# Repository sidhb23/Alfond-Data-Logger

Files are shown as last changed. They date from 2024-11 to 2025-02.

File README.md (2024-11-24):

# Alfond-Data-Logger

Capstone Project of Alex Picard and Siddhartha Bajracharya.

The project is a custom PCB designed to monitor the Ice and Ambient temperature/humidity of the Alfond Sports Arena. This repository contains the code for the STM32U545VET6 microcontroller used in the custom PCB. It also contains the schematic and layout files of the designed PCB. 

A python script is also included which is used to receive/send data from a Raspberry Pi to the PCB through Zigbee

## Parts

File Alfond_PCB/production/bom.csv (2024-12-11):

Designator | Footprint | Quantity | Value | LCSC Part #
_7, _6, _5, _4, _3, _2, |  | 7
BRD1 | 128x64OLED | 1 | SSD1306
C1 | 0603 | 1 | 4u7
C10, C14, C2, C3, C4, C5, C6, C7, C8, C9 | 0402 | 10 | 100n
C11, C12 | 0402 | 2 | 10p
C13 | 0805 | 1 | 10u
C15 | 0805 | 1 | 2.2u
D1, D2 | SOT-23-5 | 2 | SOT-23-5
D3 | 0603 | 1 | RED
D4 | 0805 | 1 | RED
INA+, INA- | PinHeader_1x01_P2.54mm_Vertical | 2 | PinHeader_1x01_P2.54mm_Vertical
INA260 | 1X08_ROUND_70 | 1 | 1X08_ROUND_70
J3 | PinHeader_1x05_P2.54mm_Vertical | 1 | Conn_01x05_Pin
J5 | USB_Micro-B_Wuerth_629105150521 | 1 | USB_B_Micro
MOD1 | XBEE-20_THT | 1 | XB24CZ7PIT-004 | XB24CZ7PIT-004
MS8607 | 1X05_ROUND | 1 | 1X05_ROUND
P1 | JST_PHR-2 | 1 | PHR-2
R1 | 0402 | 1 | 4.7k
R3 | 0402 | 1 | 1k
R4, R5 | 0402 | 2 | 10k
R6, R7 | 0402 | 2 | 1.5k
S1, S2 | Switch_Tactile_THT_B3F-1xxx | 2 | PTS645SM43SMTR92_LFS | PTS645SM43SMTR92 LFS
SW1 | SW_SPDT_PCM12 | 1 | SW_SPDT
U1 | TO-92_Inline | 1 | DS18B20
U2 | LQFP-100_14x14mm_P0.5mm | 1 | STM32U545VETx
U5 | SOT-23-5_M5_MCH | 1 | MIC5219-3.3YM5-TR
Y1 | Crystal_SMD_3225-4Pin_3.2x2.5mm | 1 | 16MHz

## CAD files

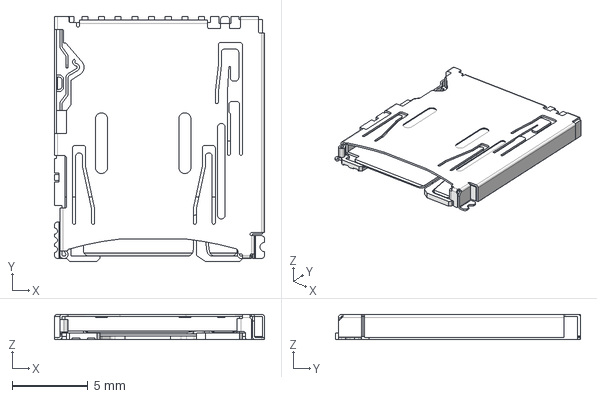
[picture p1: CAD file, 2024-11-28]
Alfond_PCB/Models/DM3AT-SF-PEJM5.stp
13.8 x 16.2 x 1.68 mm

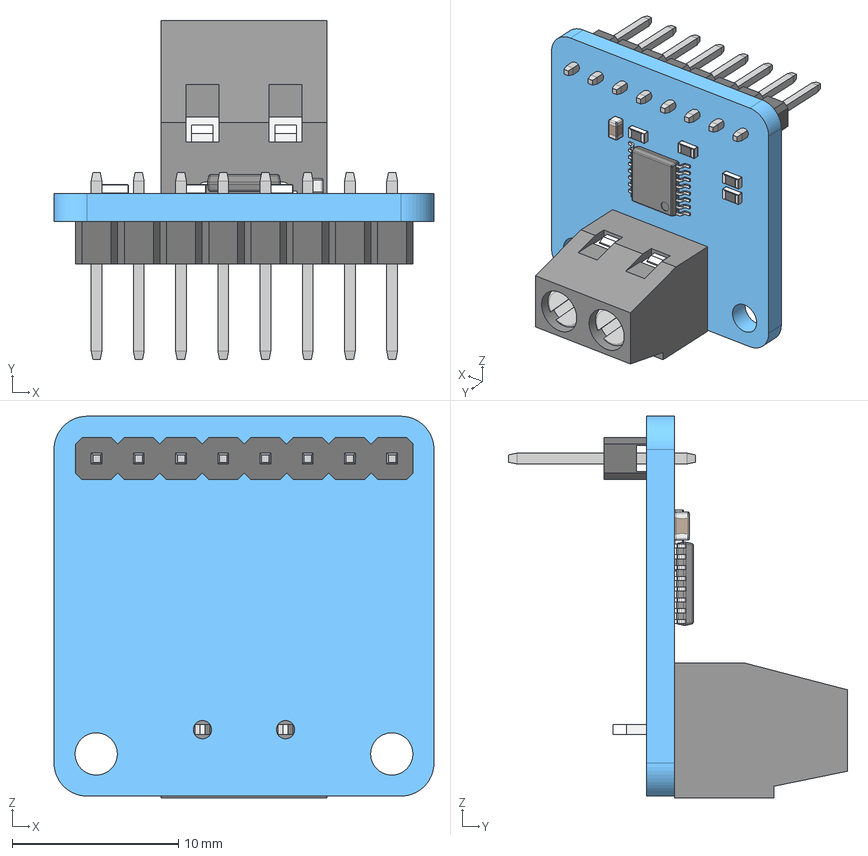
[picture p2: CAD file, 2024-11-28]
Alfond_PCB/Models/Adafruit INA260 Breakout Board.step
22.9 x 20.4 x 23.0 mm
PCB
BODY-TSSOP
LEAD-TSSOP x 16
Resistor x 4
Capacitor
Screw Terminal Block
1x8 Male Headers

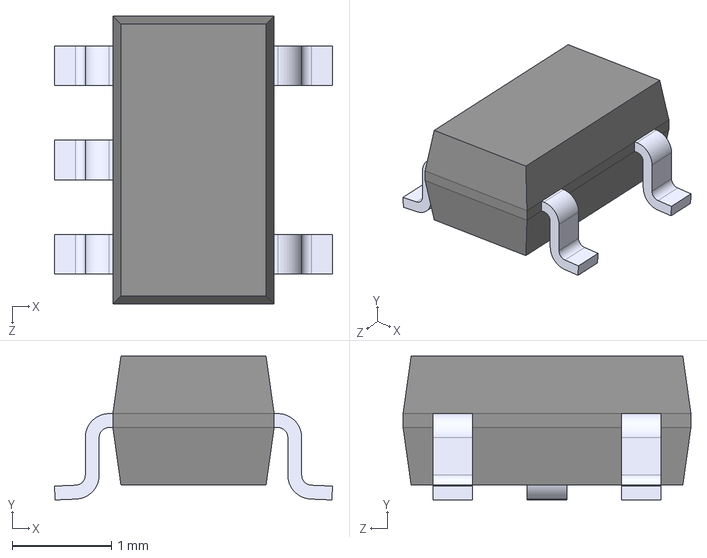
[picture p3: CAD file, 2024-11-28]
Alfond_PCB/Footprints/MAX40200AUK_T/MAX40200AUK_T.step
2.80 x 1.45 x 2.90 mm

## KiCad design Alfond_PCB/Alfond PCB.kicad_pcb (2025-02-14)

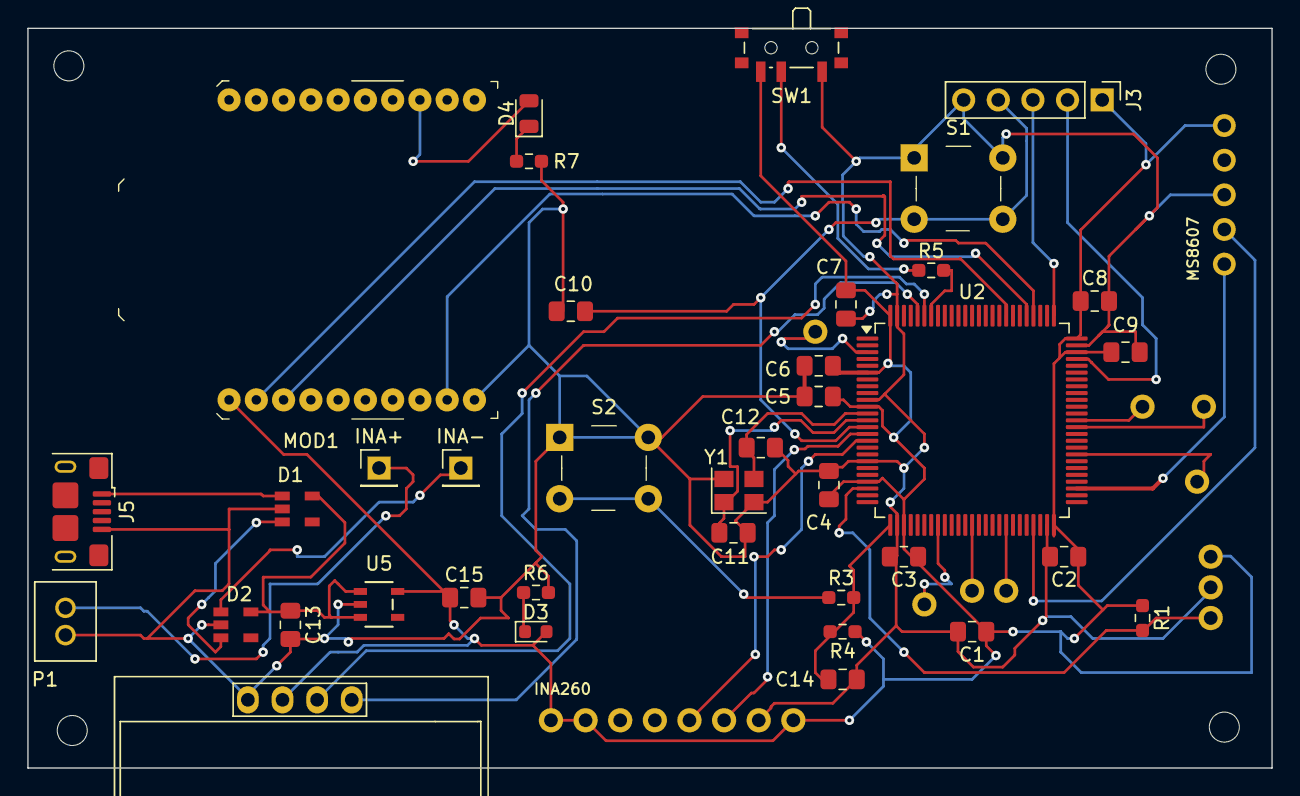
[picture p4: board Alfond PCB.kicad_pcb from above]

Board: 2 copper layers, 91.2 x 54.2 mm, 44 parts (0 on the bottom side), 29 nets.

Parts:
Brd1: SSD1306; 128x64OLED
C1: 4u7; C_0805_2012Metric_Pad1.18x1.45mm_HandSolder
C2, C3, C4, C5, C6, C7, C8, C9, C10, C14: 100n; C_0805_2012Metric_Pad1.18x1.45mm_HandSolder
C11, C12: 10p; C_0805_2012Metric_Pad1.18x1.45mm_HandSolder
C13: 10u; C_0805_2012Metric_Pad1.18x1.45mm_HandSolder
C15: 2.2u; C_0805_2012Metric_Pad1.18x1.45mm_HandSolder
D1, D2: SOT-23-5
D3: RED; LED_0603_1608Metric
D4: RED; LED_0805_2012Metric
H1, H2, H3, H4: MountingHole; MountingHole_2.2mm_M2
INA260: 1X08_ROUND_70
INA+: PinHeader_1x01_P2.54mm_Vertical
INA-: PinHeader_1x01_P2.54mm_Vertical
J3: Conn_01x05_Pin; PinHeader_1x05_P2.54mm_Vertical
J5: USB_B_Micro; USB_Micro-B_Amphenol_10118193-0001LF_Horizontal
MOD1: XB24CZ7PIT-004; XBEE-20_THT
MS8607: 1X05_ROUND
P1: PHR-2; JST_PHR-2
R1: 4.7k; R_0603_1608Metric_Pad0.98x0.95mm_HandSolder
R3: 1k; R_0603_1608Metric_Pad0.98x0.95mm_HandSolder
R4, R5: 10k; R_0603_1608Metric_Pad0.98x0.95mm_HandSolder
R6, R7: 1.5k; R_0603_1608Metric_Pad0.98x0.95mm_HandSolder
S1, S2: PTS645SM43SMTR92_LFS; Switch_Tactile_THT_B3F-1xxx
SW1: SW_SPDT; SW_SPDT_PCM12
U2: STM32U545VETx; LQFP-100_14x14mm_P0.5mm
U5: MIC5219-3.3YM5-TR; SOT-23-5_M5_MCH
Y1: 16MHz; Crystal_SMD_3225-4Pin_3.2x2.5mm

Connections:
+3.3V: Brd1.2 (VCC), C1.1, C2.1, C3.1, C4.1, C5.1, C6.1, C7.1, C8.1, C9.1, C15.1, D3.2 (A), INA260.8, INA260.Vin+, INA260.Vin-, J3.1, MOD1.1 (Vcc), MS8607.5, R1.1, R4.1, SW1.3 (C), U2.6 (VBAT), U2.11 (VDD), U2.22 (VDDA), U2.28 (VDD), U2.50 (VDD), U2.73 (VDDUSB), U2.75 (VDD), U2.100 (VDD), U5.5 (OUT)
/BOOT0: R5.2, U2.94 (PH3)
/GPIO_INPUT_Button: C14.1, R3.2, R4.2, U2.26 (PA3)
/GPIO_SLEEP_XBEE: MOD1.9 (~DTR/SLRQ/DI8), U2.79 (PC11)
/HSE_IN: C12.1, U2.12 (PH0), Y1.3
/HSE_OUT: C11.1, U2.13 (PH1), Y1.1
/I2C1_SCL: Brd1.3 (SCL), U2.95 (PB8)
/I2C1_SDA: Brd1.4 (SDA), U2.96 (PB9)
/I2C2_SCL: MS8607.2, U2.47 (PB10)
/I2C2_SDA: MS8607.1, U2.53 (PB14)
/I2C3_SCL: INA260.6, U2.15 (PC0)
/I2C3_SDA: INA260.5, U2.16 (PC1)
/INA+: INA+.1, P1.2
/INA-: D2.1, INA-.1
/NRST: C10.1, J3.4, S1.3, S1.4, U2.14 (NRST)
/PWR_LED_K: D3.1 (K), R6.1
/PWR_LED_K2: D4.1 (K), R7.1
/SWD_CLK: J3.3, U2.76 (PA14)
/SWD_DIO: J3.2, U2.72 (PA13)
/UART4_TX: R1.2, U2.23 (PA0)
/UART5_RX: MOD1.2 (DOUT), U2.83 (PD2)
/UART5_TX: MOD1.3 (DIN/~Config), U2.80 (PC12)
/V_USB: D1.1, J5.1 (VBUS)
EN: D1.3, D2.3
GND: Brd1.1 (GND), C1.2, C2.2, C3.2, C4.2, C5.2, C6.2, C7.2, C8.2, C9.2, C10.2, C11.2, C12.2, C13.2, C14.2, C15.2, D1.2, D2.2, INA260.7, J3.5, J5.5 (GND), MOD1.10 (GND), MS8607.3, P1.1, R6.2, R7.2, S1.1, S1.2, S2.1, S2.2, SW1.1 (A), U2.10 (VSS), U2.19 (VSSA), U2.27 (VSS), U2.49 (VSS), U2.74 (VSS), U2.99 (VSS), U5.2 (GND), Y1.2, Y1.4
unnamed: C13.1, D1.5, D2.5, U5.1 (IN), U5.3 (EN)
unnamed: D4.2 (A), MOD1.13 (ON/~SLEEP)
unnamed: R3.1, S2.3, S2.4
unnamed: R5.1, SW1.2 (B)

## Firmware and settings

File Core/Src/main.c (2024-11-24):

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
/* Includes ------------------------------------------------------------------*/
#include "main.h"

/* USER CODE BEGIN Includes */
#include "ssd1306.h"
#include "ms8607.h"
#include <stdio.h>
#include <string.h>
/* USER CODE END Includes */

/* USER CODE BEGIN PD */
#define MS8607_ADDRESS 0x76

// Command Definitions
#define CMD_READ_PROM 0xA0
#define CMD_READ_TEMP 0x58
#define CMD_READ_PRESS 0x40
#define CMD_RESET 0x1E

#define INA260_I2C_ADDRESS  0x40 << 1
#define REG_CURRENT         0x01
#define REG_BUS_VOLTAGE     0x02
#define REG_POWER           0x03
/* USER CODE END PD */


I2C_HandleTypeDef hi2c1;
I2C_HandleTypeDef hi2c2;
I2C_HandleTypeDef hi2c3;

UART_HandleTypeDef huart4;
UART_HandleTypeDef huart5;
UART_HandleTypeDef huart3;

void SystemClock_Config(void);
static void SystemPower_Config(void);
static void MX_GPIO_Init(void);
static void MX_ICACHE_Init(void);
static void MX_I2C1_Init(void);
static void MX_I2C2_Init(void);
static void MX_UART4_Init(int baud);
static void MX_UART5_Init(void);
static void MX_USART3_UART_Init(void);
static void MX_I2C3_Init(void);

/* USER CODE BEGIN PFP */
int presence = 0, isRxed = 0;
  uint8_t RxData[8], Temp_LSB = 0, Temp_MSB = 0;
  int16_t Temp;
  float temp_DS18B20;
  void INA260_Init();
  float INA260_ReadCurrent();
  float INA260_ReadVoltage();
  float INA260_ReadPower();
/* USER CODE END PFP */

/* USER CODE BEGIN 0 */
int DS18B20_start (void)
{
		uint8_t data = 0xF0;
		MX_UART4_Init(9600);
		HAL_UART_Transmit(&huart4, &data, 1, 100);
		if (HAL_UART_Receive(&huart4, &data, 1, 1000) != HAL_OK) return -1; // failed.. check connection
		MX_UART4_Init(115200);
		if (data == 0xf0) return -2; //error no device detected
		return 1;
}

void DS18B20_Write (uint8_t data)
{
	uint8_t buffer[8];
	for (int i = 0; i < 8; i++) {
		if ((data & (1<<i)) != 0){  // if the bit is high
			buffer[i] = 0xFF; // send a 1
		} else {
			buffer[i] = 0x00; // send a 0
		}
	}

	HAL_UART_Transmit(&huart4, buffer, 8, 1000);
}

uint8_t DS18B20_Read(void)
{
    uint8_t value = 0;
    for (int i = 0; i < 8; i++)
    {
        uint8_t tx_byte = 0xFF;  // Transmit request for a read time slot
        uint8_t rx_byte = 0;

        // Transmit and receive each bit
        if (HAL_UART_Transmit(&huart4, &tx_byte, 1, 1000) != HAL_OK)
        {
            // Handle transmission error
        }

        if (HAL_UART_Receive(&huart4, &rx_byte, 1, 1000) != HAL_OK)
        {
            // Handle reception error
        }

        // Store the received bit in RxData for debugging
        RxData[i] = rx_byte;

        // Interpret received bit as 1 if rx_byte == 0xFF, otherwise 0
        if (rx_byte == 0xFF)
        {
            value |= (1 << i); // Set the bit in value
        }
    }
    return value;
}


void HAL_UART_RxCpltCallback(UART_HandleTypeDef *huart)
{
	isRxed = 1;
}
/* USER CODE END 0 */

/**
  * @brief  The application entry point.
  * @retval int
  */
int main(void)
{

  /* USER CODE BEGIN 1 */
	uint16_t prom[6];

	  char snum[15] = "Hello world";
	  double temperature;
	  float pressure;
	  float humidity;
  /* USER CODE END 1 */

  /* MCU Configuration--------------------------------------------------------*/

  /* Reset of all peripherals, Initializes the Flash interface and the Systick. */
  HAL_Init();

  /* Configure the system clock */
  SystemClock_Config();

  /* Configure the System Power */
  SystemPower_Config();

  /* Initialize all configured peripherals */
  MX_GPIO_Init();
  MX_ICACHE_Init();
  MX_I2C1_Init();
  MX_I2C2_Init();
  MX_UART4_Init(9600);
  MX_UART5_Init();
  MX_USART3_UART_Init();
  MX_I2C3_Init();
  /* USER CODE BEGIN 2 */
  SSD1306_Init();
  INA260_Init();
  /* USER CODE END 2 */

  /* Infinite loop */
  /* USER CODE BEGIN WHILE */
  while (1)
    {
	  MS8607_ReadPROM(&hi2c2, prom);
	  temperature = MS8607_ReadTemperature(&hi2c2, prom);

	    	  // Convert temperature to string for display
	    	  snprintf(snum, sizeof(snum), "%.2lf C", temperature);

	    	  // Update the display
	    	  SSD1306_GotoXY(0, 0);
	    	  SSD1306_Puts(snum, &Font_7x10, SSD1306_COLOR_WHITE);
	    	  SSD1306_UpdateScreen();
	    	  strcat(snum, "\n\r");
	    	  HAL_UART_Transmit(&huart5, (uint8_t*)snum, strlen(snum), 100);
	    	  pressure = MS8607_ReadPressure(&hi2c2, prom, temperature);
	    	  // Convert temperature to string for display
	    	  snprintf(snum, sizeof(snum), "%.2f HPa", pressure);

	    	  // Update the display
	    	  SSD1306_GotoXY(0, 20);
	    	  SSD1306_Puts(snum, &Font_7x10, SSD1306_COLOR_WHITE);
	    	  SSD1306_UpdateScreen();
	    	  strcat(snum, "\n\r");
	    	  HAL_UART_Transmit(&huart5, (uint8_t*)snum, strlen(snum), 100);
	    	  humidity = MS8607_ReadHumidity(&hi2c2);
	    	  // Convert temperature to string for display
	    	  snprintf(snum, sizeof(snum), "%.2f%%", humidity);
	    	  // Update the display
	    	  SSD1306_GotoXY(0, 40);
	    	  SSD1306_Puts(snum, &Font_7x10, SSD1306_COLOR_WHITE);
	    	  SSD1306_UpdateScreen();
	    	  strcat(snum, "\n\r");
	    	  HAL_UART_Transmit(&huart5, (uint8_t*)snum, strlen(snum), 100);
	    	  presence = DS18B20_start();
	    	  	  DS18B20_Write(0xCC); // skip ROM
	    	  	  DS18B20_Write(0x44); // convert temperature

	    	  	  presence = DS18B20_start();
	    	  	  DS18B20_Write(0xCC); // skip ROM
	    	  	  DS18B20_Write(0xBE); // read scratchpad

	    	  	  Temp_LSB = DS18B20_Read();
	    	  	  Temp_MSB = DS18B20_Read();
	    	  	  Temp = (Temp_MSB<<8) | Temp_LSB;
	    	  	  temp_DS18B20 = (float)Temp/16.0; // resolution is 0.0625
	    	  	snprintf(snum, sizeof(snum), "%.2f C Ice", temp_DS18B20);

	    	  		    	  // Update the display
	    	  		    	  SSD1306_GotoXY(50, 40);
	    	  		    	  SSD1306_Puts(snum, &Font_7x10, SSD1306_COLOR_WHITE);
	    	  		    	  SSD1306_UpdateScreen();
	    	  		    	  strcat(snum, "\n\r");
	    	  		    	  HAL_UART_Transmit(&huart5, (uint8_t*)snum, strlen(snum), 100);
	    	  		    	HAL_Delay(1000);
	    	  		    	SSD1306_Fill(SSD1306_COLOR_BLACK);
	    	  		    	float current = INA260_ReadCurrent();
	    	  		    	snprintf(snum, sizeof(snum), "%.2f A", current);
	    	  		    	SSD1306_GotoXY(0, 0);
	    	  		    		    	  		    	  SSD1306_Puts(snum, &Font_7x10, SSD1306_COLOR_WHITE);
	    	  		    		    	  		    	  SSD1306_UpdateScreen();
	    	  		    	        float voltage = INA260_ReadVoltage();
	    	  		    	      snprintf(snum, sizeof(snum), "%.2f V", voltage);
	    	  		    	      SSD1306_GotoXY(0, 20);
	    	  		    	      	    	  		    	  SSD1306_Puts(snum, &Font_7x10, SSD1306_COLOR_WHITE);
	    	  		    	      	    	  		    	  SSD1306_UpdateScreen();
	    	  		    	        float power = INA260_ReadPower();
	    	  		    	      snprintf(snum, sizeof(snum), "%.2f W", power);
	    	  		    	      SSD1306_GotoXY(0, 40);
	    	  		    	      	    	  		    	  SSD1306_Puts(snum, &Font_7x10, SSD1306_COLOR_WHITE);
	    	  		    	      	    	  		    	  SSD1306_UpdateScreen();
	    	  HAL_Delay(1000); // Update every second
    /* USER CODE END WHILE */

    /* USER CODE BEGIN 3 */
  }
  /* USER CODE END 3 */
}

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
/* USER CODE BEGIN 4 */
void INA260_Init() {
    // INA260 uses default configuration; no initialization required.
	 uint8_t config_data[] = {0x00, 0x00};  // Example configuration
	    HAL_I2C_Master_Transmit(&hi2c3, INA260_I2C_ADDRESS << 1, config_data, sizeof(config_data), HAL_MAX_DELAY);
}

// Read raw data from a register
uint16_t INA260_ReadRegister(uint8_t reg) {
    uint8_t data[2] = {0};
    HAL_I2C_Master_Transmit(&hi2c3, INA260_I2C_ADDRESS, &reg, 1, HAL_MAX_DELAY);
    HAL_I2C_Master_Receive(&hi2c3, INA260_I2C_ADDRESS, data, 2, HAL_MAX_DELAY);

    return (data[0] << 8) | data[1];
}

// Convert current register value to amperes
float INA260_ReadCurrent() {
    int16_t raw_current = (int16_t)INA260_ReadRegister(REG_CURRENT);
    return raw_current * 0.00125;  // Conversion factor: 1.25 mA/bit
}

// Convert voltage register value to volts
float INA260_ReadVoltage() {
    uint16_t raw_voltage = INA260_ReadRegister(REG_BUS_VOLTAGE);
    return raw_voltage * 0.00125;  // Conversion factor: 1.25 mV/bit
}

// Convert power register value to watts
float INA260_ReadPower() {
    uint16_t raw_power = INA260_ReadRegister(REG_POWER);
    return raw_power * 0.01;  // Conversion factor: 10 mW/bit
}
/* USER CODE END 4 */

/**
  * @brief BSP Push Button callback
  * @param Button Specifies the pressed button
  * @retval None
  */


/**
  * @brief  This function is executed in case of error occurrence.
  * @retval None
  */
void Error_Handler(void)
{
  /* USER CODE BEGIN Error_Handler_Debug */
  /* User can add his own implementation to report the HAL error return state */
  __disable_irq();
  while (1)
  {
  }
  /* USER CODE END Error_Handler_Debug */
}

#ifdef  USE_FULL_ASSERT
/**
  * @brief  Reports the name of the source file and the source line number
  *         where the assert_param error has occurred.
  * @param  file: pointer to the source file name
  * @param  line: assert_param error line source number
  * @retval None
  */
void assert_failed(uint8_t *file, uint32_t line)
{
  /* USER CODE BEGIN 6 */
  /* User can add his own implementation to report the file name and line number,
     ex: printf("Wrong parameters value: file %s on line %d\r\n", file, line) */
  /* USER CODE END 6 */
}
#endif /* USE_FULL_ASSERT */

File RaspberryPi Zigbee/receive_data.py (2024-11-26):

import serial
import csv
from datetime import datetime

# Open serial connection to XBee connected via USB
ser = serial.Serial('/dev/ttyUSB0', 57600, timeout=1)

# File to store data
output_file = "sensor_data.csv"

# Create or open the CSV file and write the header
with open(output_file, mode='a', newline='') as file:
    writer = csv.writer(file)
    # Write header if file is empty
    if file.tell() == 0:
        writer.writerow(["Timestamp", "Data"])

print("Waiting for data...")

while True:
    try:
        if ser.in_waiting > 0:
            # Read data from serial port
            data = ser.readline().decode('utf-8').strip()
            print(f"Received: {data}")
            
            # Append data to the CSV file with a timestamp
            with open(output_file, mode='a', newline='') as file:
                writer = csv.writer(file)
                timestamp = datetime.now().strftime("%Y-%m-%d %H:%M:%S")
                writer.writerow([timestamp, data])
                print("Data saved to CSV.")
    except KeyboardInterrupt:
        print("Exiting...")
        break
    except Exception as e:
        print(f"Error: {e}")

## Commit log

2024-11-21 Made the U545 project the primary project rather than zipping the project
    [629105150521 (rev1).stp, Adafruit INA260 Breakout Board.f3d, Adafruit INA260 Breakout Board.step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]
2024-11-24 added the Raspberry Pi script to the new main branch and also added README
2024-11-24 changed project files to the most recent changes
    [629105150521 (rev1).stp, Adafruit INA260 Breakout Board.f3d, Adafruit INA260 Breakout Board.step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]
2024-11-25 Further PCB design
    Found the issue with connecting adafruit through hole pins, and the rest of the PCB along with connecting more components
    [629105150521 (rev1).stp, Adafruit INA260 Breakout Board.f3d, Adafruit INA260 Breakout Board.step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]
2024-11-27 Removed layers
    Had extra copper layers that weren't used, and forgot to comment on the last push, but it was creating a fully connected pcb
    [Alfond PCB-B_Cu.gbl, Alfond PCB-B_Cu.gbr, Alfond PCB-B_Mask.gbr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]
2024-11-27 Footprints Used
    Added all the external footprints needed to properly view the PCB and schematic
2024-11-27 Updated the schematic and PCB
    The schematic and PCB had a generic MIC symbol and footprint, however the MIC that was ordered had 5 pins while the one in the PCB had 8.
    [629105150521 (rev1).stp, Adafruit INA260 Breakout Board.f3d, Adafruit INA260 Breakout Board.step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]
2024-11-27 Delete Alfond_PCB (1) directory
    Added updated pcb changes, but it got added as a new directory and not changing the current one
    [629105150521 (rev1).stp, Adafruit INA260 Breakout Board.f3d, Adafruit INA260 Breakout Board.step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]
2024-11-27 Update to PCB and Footprints
    The PCB was updated to the correct MIC ordered from Digikey, and the footprint was added to the footprint folders.
    [Alfond PCB.kicad_pcb, Alfond PCB.kicad_sch]
2024-11-28 fixed few errors
    [Alfond PCB.kicad_pcb, Alfond PCB.kicad_sch]
2024-11-28 PCB changes
    Added text for project name and group members, along with changing capacitor 14 from a footprint that wasn't working with one that is.
    [Adafruit INA260 Breakout Board.step, Alfond PCB.kicad_pcb, Alfond PCB.kicad_sch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]
2024-11-28 Final PCB Changes
    Changed the Schottky diodes to the MAX40200 diodes
    [Alfond PCB.kicad_pcb, Alfond PCB.kicad_sch, MAX40200AUK_T.step]
2024-11-28 Added test points
    Added test points for possible debugging of PCB
    [Alfond PCB.kicad_pcb]
2024-12-11 Latest PCB Changes
    PCB changes for the PCB order that was made on 12/07/2024
    [bom.csv, designators.csv, positions.csv]
2025-01-31 PCB order 2
2025-02-05 made improvments to pcb
    [Alfond PCB.kicad_pcb, Alfond PCB.kicad_sch]
2025-02-14 made changes to switch placement
    [Alfond PCB.kicad_pcb, Alfond PCB.kicad_sch]
2025-03-11 Final PCB Code

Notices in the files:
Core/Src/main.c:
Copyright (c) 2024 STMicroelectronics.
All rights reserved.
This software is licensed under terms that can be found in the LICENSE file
